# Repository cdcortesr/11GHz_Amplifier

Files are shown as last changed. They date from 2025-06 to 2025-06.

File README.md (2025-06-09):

# RF Power Amplifier PCB Design for Satellite Transmitter (11 GHz)

<picture>
  <source media="(prefers-color-scheme: dark)" srcset="https://raw.githubusercontent.com/cdcortesr/RF-Power-Amplifier-11GHz-/refs/heads/main/3Dview.JPG">
  <source media="(prefers-color-scheme: light)" srcset="https://raw.githubusercontent.com/cdcortesr/RF-Power-Amplifier-11GHz-/refs/heads/main/3Dview.JPG">
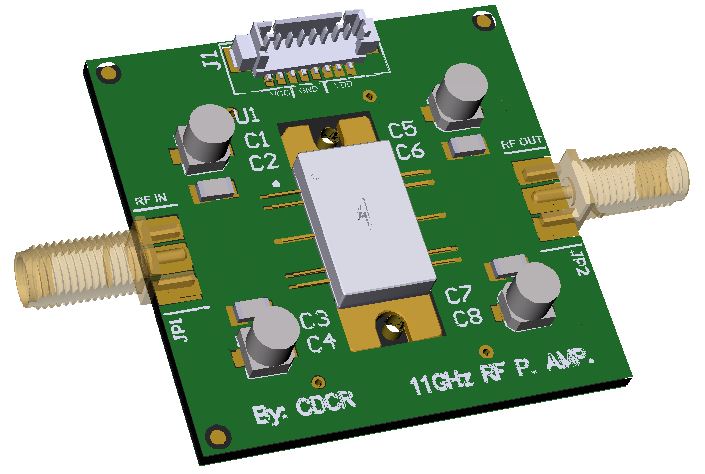
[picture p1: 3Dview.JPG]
  
</picture>

• Designed a high-power RF amplifier PCB module that is intended for use in a satellite communication transmitter at 11 GHz.

• Specifications: The module is capable of delivering up to 44 dBm output power, Power Added Efficiency (PAE) in the range of 15 to 25 percent and a P1DB of 23dBm.

• Utilized a high-performance Wolfspeed GaN-on-SiC MMIC (CMPA601C025F), selected for its ability to operate efficiently at Ku-band frequencies with high output power and linearity.

• Designed on RT/duroid® 6010 high-frequency laminate (Dk=10.2) to ensure characteristic impedance of the input and output microstrip transmission line, low dielectric loss and stable performance at 11 GHz.

• Included instructions for the PCB manufacturer to drill a PCB cavity beneath the IC footprint to meet physical dimensions and thermal management requirements of the GaN device, ensuring efficient heat transfer and mechanical stability.

• With a module like this is possible to achieve a received power of -82.26 dBm in a receiver station that is at 1000 km assuming the following link:

<picture>
  <source media="(prefers-color-scheme: dark)" srcset="https://raw.githubusercontent.com/cdcortesr/RF-Power-Amplifier-11GHz-/refs/heads/main/LinkCalculation.png">
  <source media="(prefers-color-scheme: light)" srcset="https://raw.githubusercontent.com/cdcortesr/RF-Power-Amplifier-11GHz-/refs/heads/main/LinkCalculation.png">
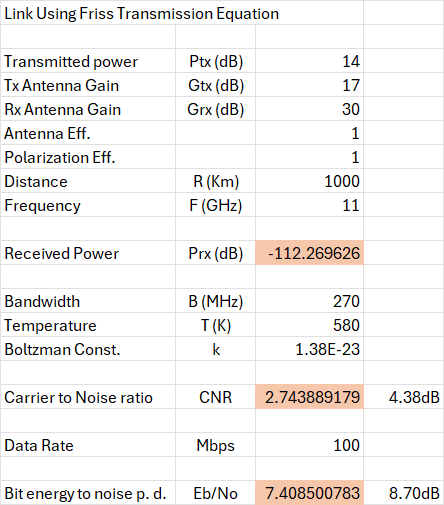
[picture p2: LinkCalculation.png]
  
</picture>

• An Energy per bit to noise power spectral density ratio of 8.70 dB allows for a BER of 10^-4 using a modulation scheme like QPSK. Furhter BER reduction can be obtained by using Forward Error Correction such as Reed Solomon Codes.

<picture>
  <source media="(prefers-color-scheme: dark)" srcset="https://upload.wikimedia.org/wikipedia/commons/thumb/7/77/PSK_BER_curves.svg/800px-PSK_BER_curves.svg.png">
  <source media="(prefers-color-scheme: light)" srcset="https://upload.wikimedia.org/wikipedia/commons/thumb/7/77/PSK_BER_curves.svg/800px-PSK_BER_curves.svg.png">
  a.
</picture>

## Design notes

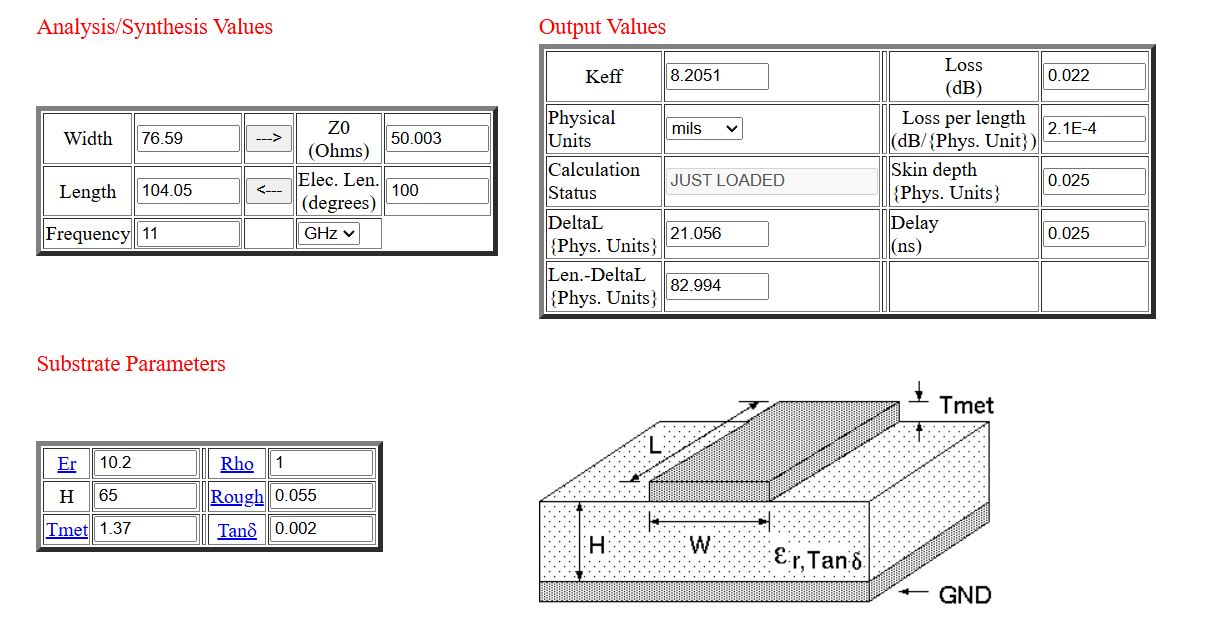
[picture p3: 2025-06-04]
Synthesis_Ampl.JPG

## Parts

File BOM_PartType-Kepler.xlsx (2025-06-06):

Comment | Description | Designator | Footprint | LibRef | Quantity
Panasonic 10SVP10M | CAP ALUM 10UF 10V 20% SMD | C1, C4, C5, C8 | PCB-11675369-2 | CMP-11675369-3 | 4
AVX Interconnect / Elco 12061C473KAT2A | CAP CER 0.047UF 100V X7R 1206 | C2, C3, C6, C7 | CAPC3216X94X50ML20T25 | CMP-126540-2 | 4
Molex 53398-0871 | Headers & Wire Housings VERTICAL HDR SMT 8P | J1 | PCB-330964-1 | CMP-330964-5 | 1
Molex 73251-2120 | Rf Coax Conn, Sma, Jack, 50 Ohm, Pcb | JP1, JP2 | PCB-gjx2rcg91tbhfhdn1i9r-1 | CMP-4dee84f7198e9229-5 | 2
Wolfspeed CMPA601C025F | RF Amp Module Single Power Amp 12GHz 28V 11-Pin Case 440213 | U1 | Wolfspeed CMPA601C025F-Footprint-1 | CMP-1f77d3c5abf7c0b0-10 | 1

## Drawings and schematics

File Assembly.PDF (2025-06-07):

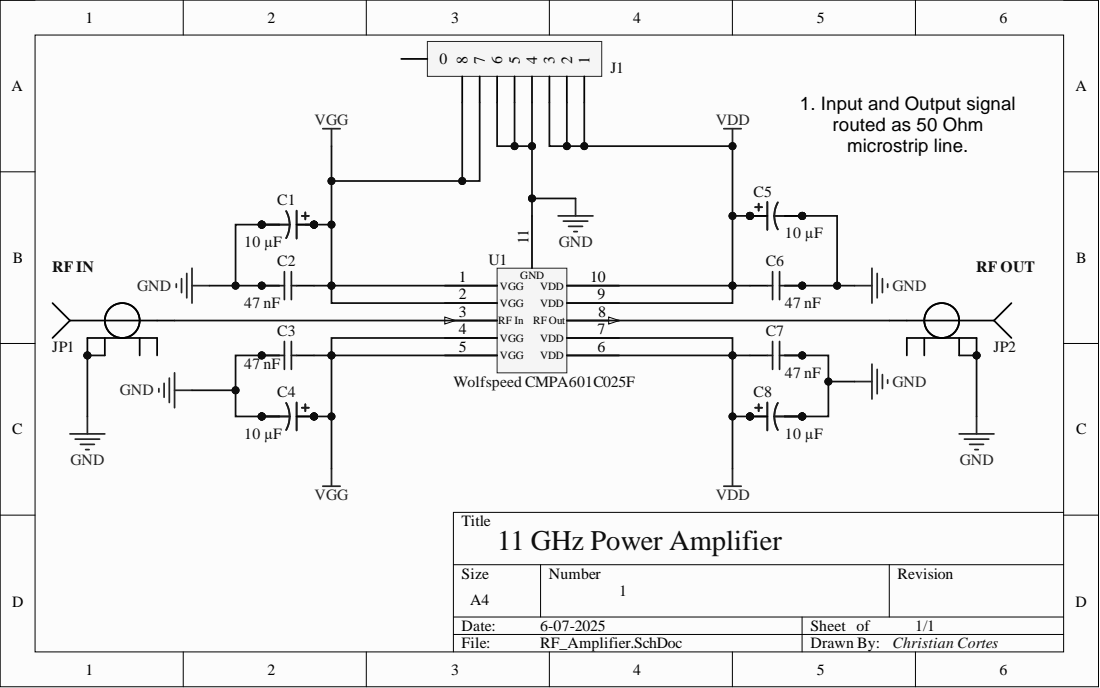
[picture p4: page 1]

1. Input and Output signal routed as 50 Ohm microstrip line.

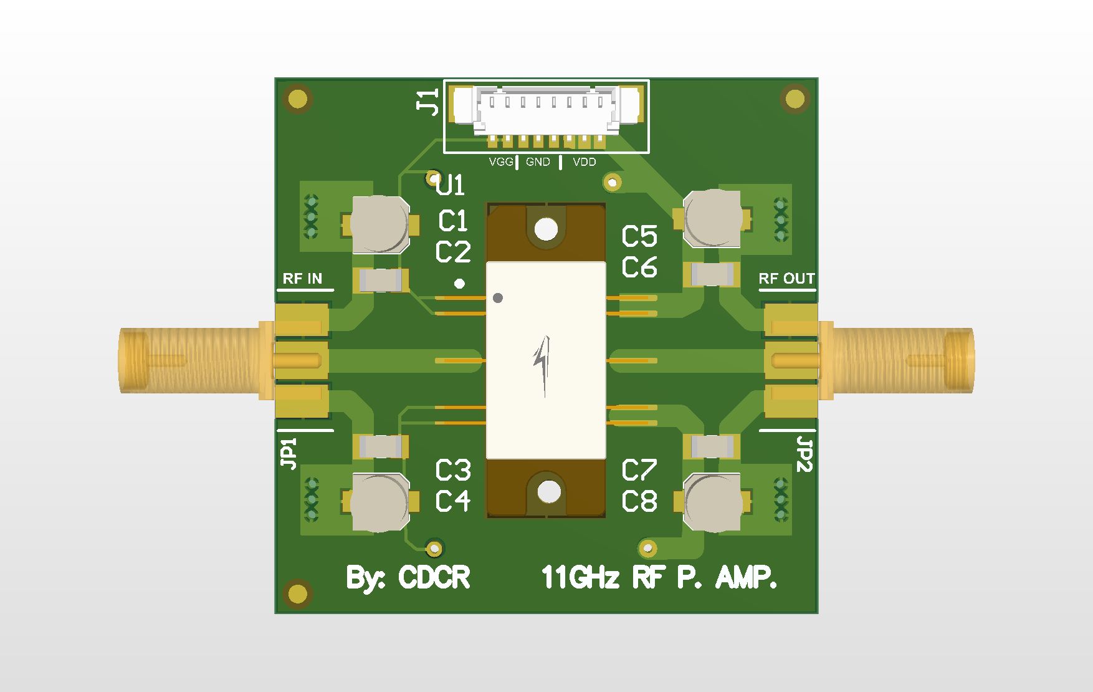
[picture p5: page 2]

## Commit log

2025-06-04 50 Ohm microstrip synthesis
2025-06-07 Updated Assembly PDF
